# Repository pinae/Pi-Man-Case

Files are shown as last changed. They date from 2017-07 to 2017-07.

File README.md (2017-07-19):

# Pi-Man-Case
A case for a Raspberry-powered game console.

This design is based on a 180mm acrylic sphere (175mm inner diameter). Print `lower_frame.stl` and `upper_closing.stl` to fill the mouth. Note that `lower_frame.stl` needs support material to print correctly. Two `fixing_block.stl` are needed to stabilize the construction after the mouth part is cut out of the sphere. `ring180.stl` is a stand for the finished sphere.

The lower frame has housings for 4 M3 nuts to attach the Raspberry Pi. Insert them before gluing the frame into the shere because they are hard to reach after that. If you are using short screws tighten them once before gluing the lower frame so the nuts slide the whole way into the housing.

To assemble the case you need glue that bonds acrylic and ABS (or PLA if you printed that). I used Pattex and super glue. The easiest way for the assembly is to combine the upper and lower parts of the mouth with some tape and apply the glue in one go. Put everything inside of the sphere and close it while carefully adjusting the position. You can add the fixing_blocks after the mouth is fixed. Cut away the part of the shere that occludes the mouth and sand the corners. Do not forget to add holes in the side for the HDMI and the power cable.

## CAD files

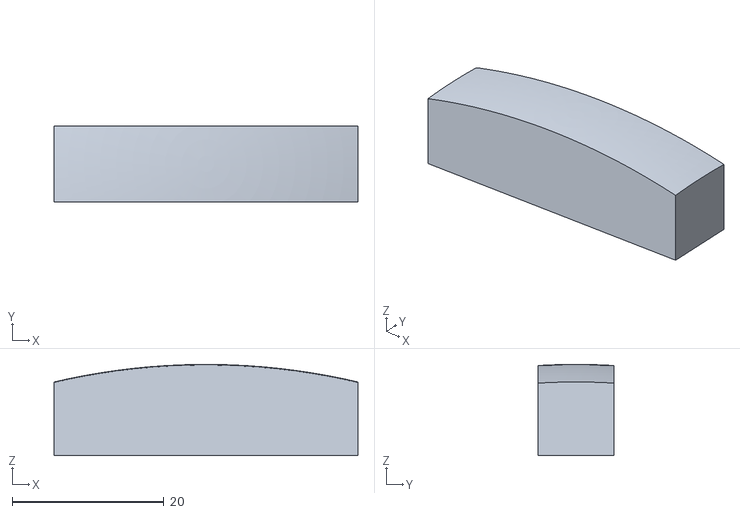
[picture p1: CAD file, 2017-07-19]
fixing_block.stl
40.0 x 10.0 x 12.0

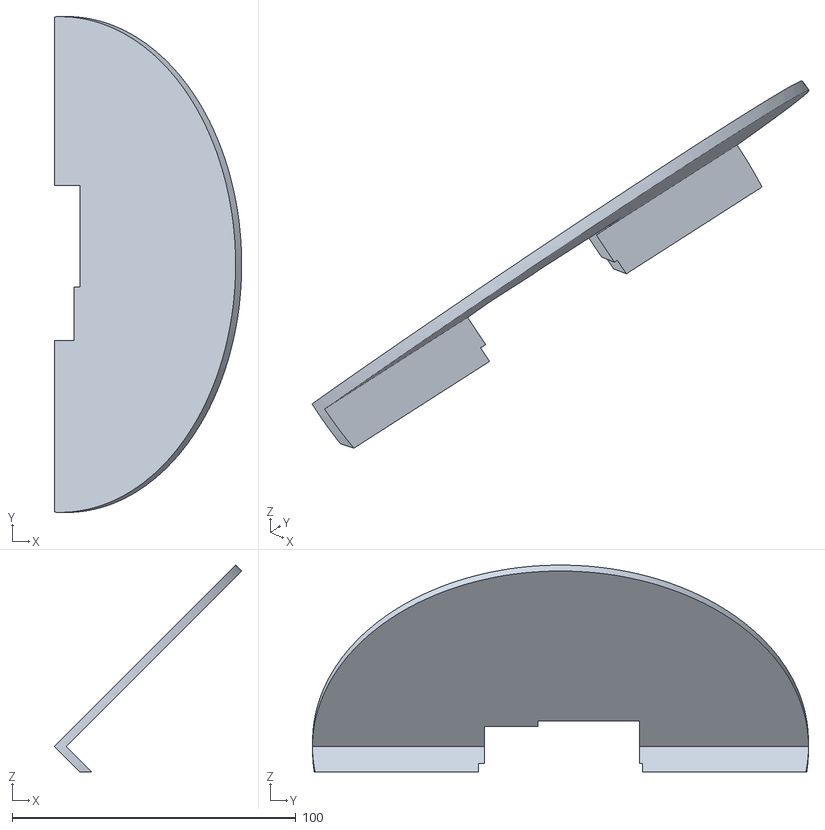
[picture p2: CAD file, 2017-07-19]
upper_closing.stl
66.1 x 174.9 x 72.9

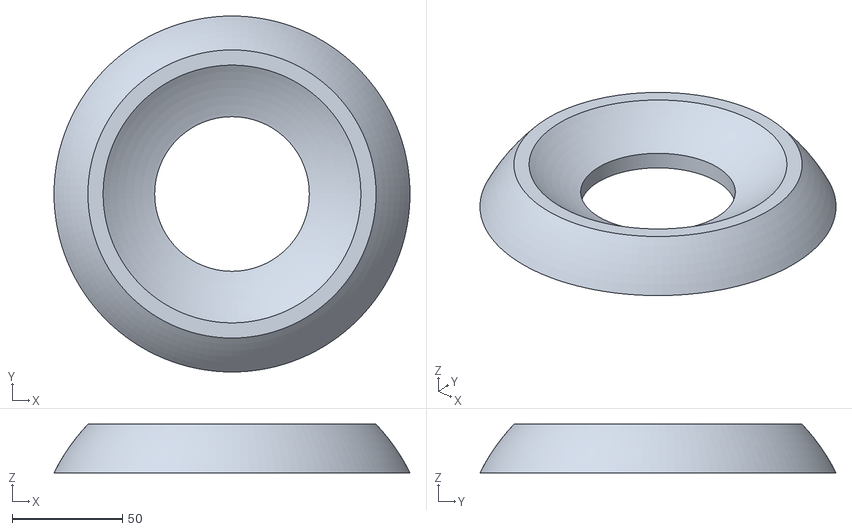
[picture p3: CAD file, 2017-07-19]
ring180.stl
161.2 x 161.2 x 22.0

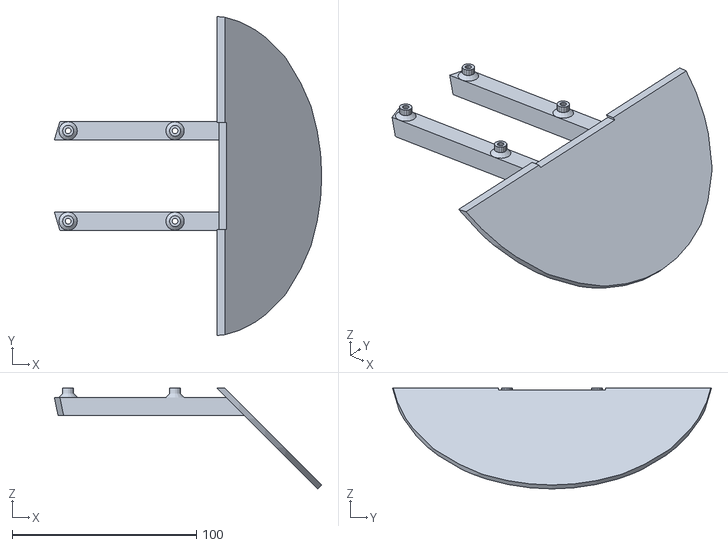
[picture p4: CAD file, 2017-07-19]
lower_frame.stl
145.1 x 173.1 x 54.7

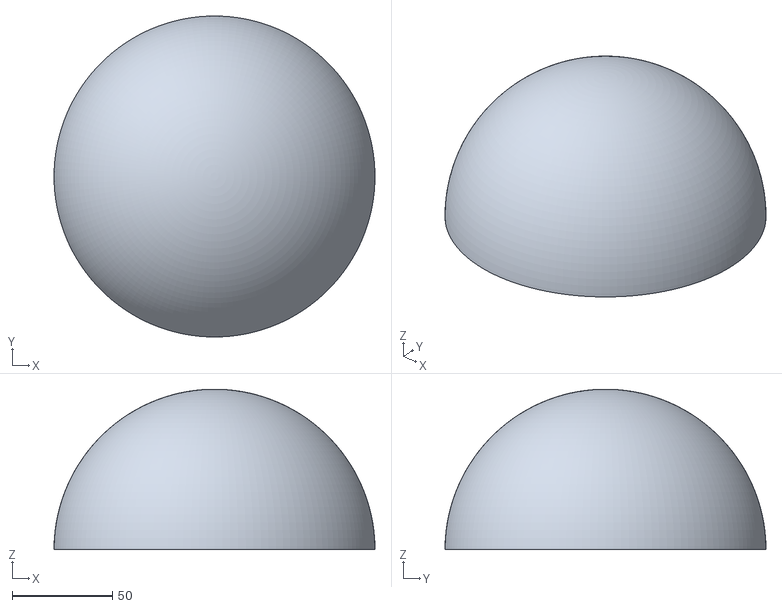
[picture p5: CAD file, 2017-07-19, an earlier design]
old_design_tests/test_sphere.stl
160.0 x 160.0 x 80.0

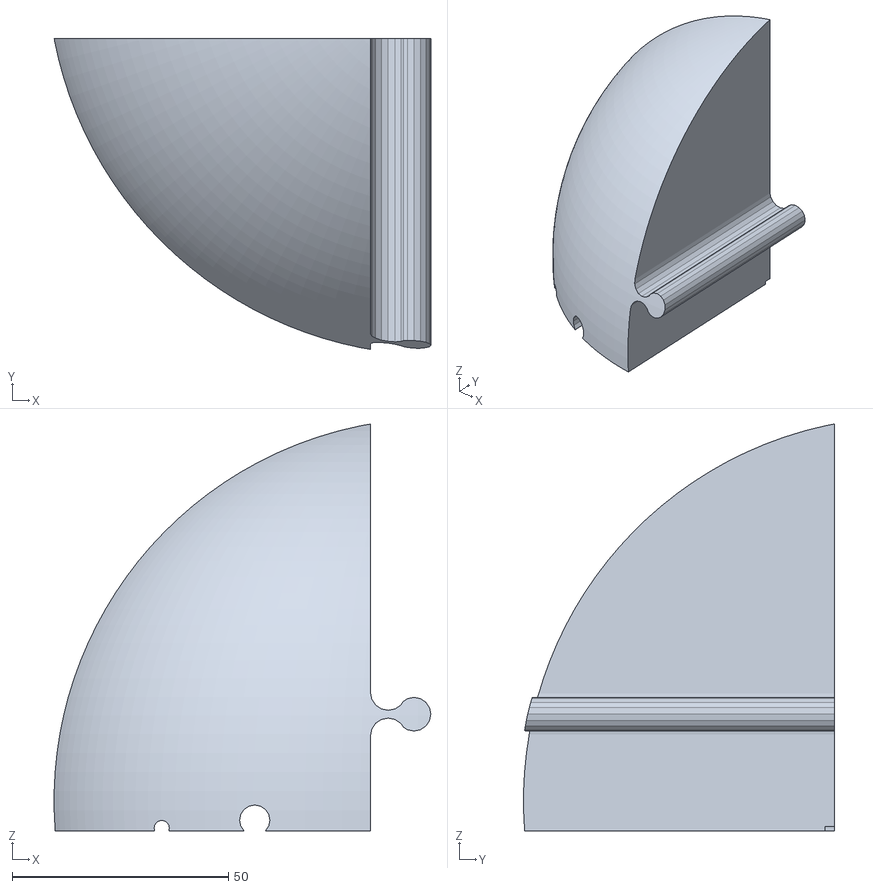
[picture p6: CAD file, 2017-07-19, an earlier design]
old_design_tests/upper_left_back_v1.stl
87.1 x 71.9 x 94.1

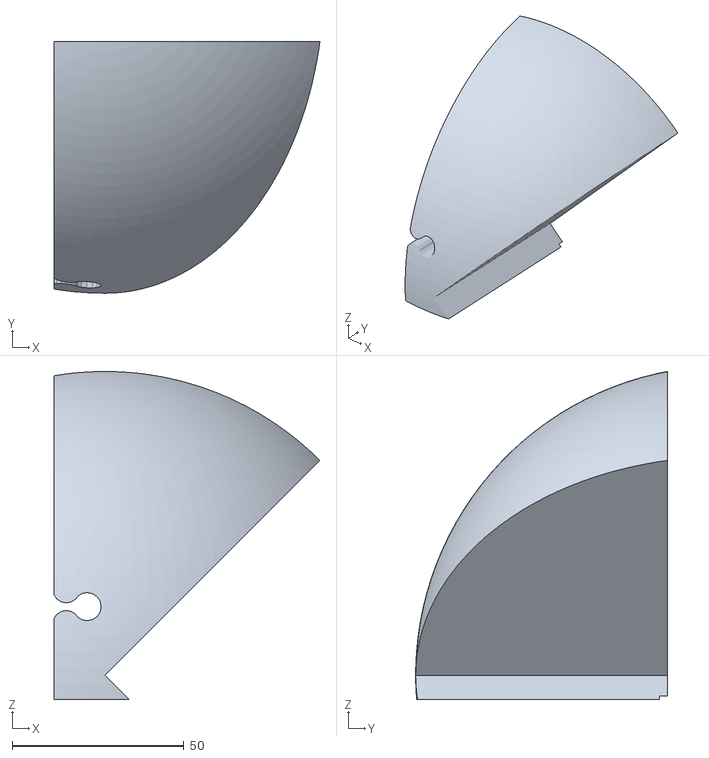
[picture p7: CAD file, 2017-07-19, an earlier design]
old_design_tests/upper_left_front_v1.stl
77.3 x 73.2 x 95.4

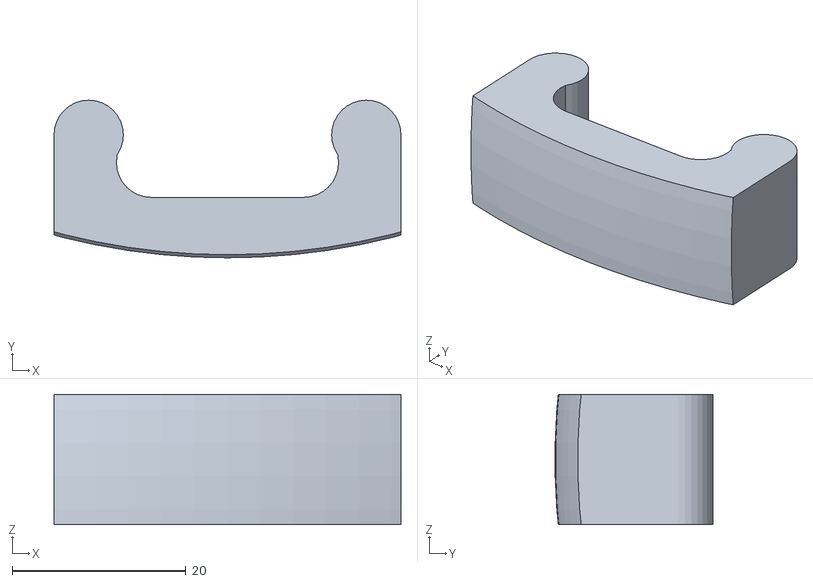
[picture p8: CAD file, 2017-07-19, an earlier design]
old_design_tests/clamp.stl
40.0 x 18.2 x 15.0

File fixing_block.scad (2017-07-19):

intersection() {
    translate([-20, -5, 0]) cube([40, 10, 15]);
    translate([0, 0, -175/2+12]) sphere(d=175, $fn=256);
}

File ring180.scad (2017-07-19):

fn=128;
difference() {
    translate([0, 0, -40]) sphere(d=180, $fn=fn);
    translate([0, 0, 180/2+0.5]) sphere(d=180, $fn=fn);
    translate([0, 0, -1]) cylinder(d=70, h=100, $fn=fn);
    translate([-100, -100, -200]) cube([200, 200, 200]);
    translate([-100, -100, 22]) cube([200, 200, 200]);
}

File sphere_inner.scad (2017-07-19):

use <raspi3.scad>;
//translate([-47, 0, -9]) color("blue") raspi3();

fn = 16;

module m3_hole() {
    difference() {
        union() {
            translate([0, 0, -3]) cylinder(d=6, h=3, $fn=fn);
            translate([0, 0, -5]) cylinder(d1=10, d2=6, h=2, $fn=fn);
            translate([0, 0, -9]) cylinder(d=10, h=4, $fn=fn);
        }
        translate([0, 0, -9]) cylinder(d=3+0.1, h=10, $fn=fn);
        translate([0, 0, -10]) cylinder(d=6.08+0.2, h=2.4+0.2+1, $fn=6);
    }
}

module mouth() {
    translate([0, -176/2, -3]) cube([176/2, 176, 3]);
    translate([-3, -176/2, -3]) cube([3, 176, 176/2+3]);
}

module frame() {
    intersection() {
        sphere(d=175, $fn=2*fn);
        union() {
            for(i=[0, 1]) {
                for(j=[0, 1]) {
                    translate([-76+i*58, -24.5+j*49, -9]) m3_hole();
                }
            }
            difference() {
                rotate([0, 45, 0]) mouth();
                translate([-78.3, -16.8-10, -9]) cube([88+50, 19, 16]);
                translate([-78.3, 2-10, -9]) cube([88+50, 18, 18]);
                translate([-78.3, 19.8-10, -9]) cube([88+50, 18, 18]);
                translate([-78.3, -19-10, -10]) cube([88+50, 58, 4]);
            }
            difference() {
                union() {
                    for(i=[0, 1]) {
                        translate([-176/2, -29.5+i*49, -24]) cube([110, 10, 10]);
                    }
                }
                for(i=[0, 1]) {
                    translate([0, -176/2, -1]) rotate([0, 45, 0]) cube([176, 176, 176]);
                    for(j=[0, 1]) {
                        translate([-76+i*58, -24.5+j*49, -29]) cylinder(d=6.5, h=24, $fn=6);
                    }
                }
            }
            /*for(i=[0, 1]) {
                for(j=[0, 1]) {
                    difference() {
                        union() {
                            translate([-74+i*58, -29.5+j*49, -17]) rotate([0, 45, 0]) cube([138, 10, 4]);
                            translate([-78+i*58, -19.5+j*49, -17]) rotate([0, 45, 180]) cube([138, 10, 4]);
                            translate([-71+i*58, -22.5+j*49, -17]) rotate([0, 45, 90]) cube([120, 10, 4]);
                            translate([-81+i*58, -26.5+j*49, -17]) rotate([0, 45, 270]) cube([120, 10, 4]);
                        }
                        translate([-76+i*58, -24.5+j*49, -19]) cylinder(d=6.5, h=4, $fn=6);
                    }
                }
                translate([-81+58/2, -29.5+i*49, -159]) cube([10, 10, 120]);
                translate([-81+58, -29.5+i*49, -184]) cube([10, 10, 120]);
                translate([7, -29.5+i*49, -131]) cube([4, 10, 120]);
            }*/
        }
    }
}

difference() {
    frame();
    translate([-100, -100, -9]) cube([200, 200, 200]);
}

/*difference() {
    frame();
    translate([-100, -100, -209]) cube([200, 200, 200]);
}*/

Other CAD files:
raspi3.scad
old_design_tests/case.scad
old_design_tests/modular_case.scad
old_design_tests/test_sphere.scad

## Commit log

2017-05-31 designed a Rapspberry Pi
    [case.scad]
2017-07-19 finished desgin
    [case.scad, clamp.stl, fixing_block.scad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]
